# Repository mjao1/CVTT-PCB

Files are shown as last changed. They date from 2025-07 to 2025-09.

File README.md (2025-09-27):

# CVTT-PCB
**Custom Embedded PCB for a Computer Vision-Based Table Tennis Robotic System**

<div align="center">
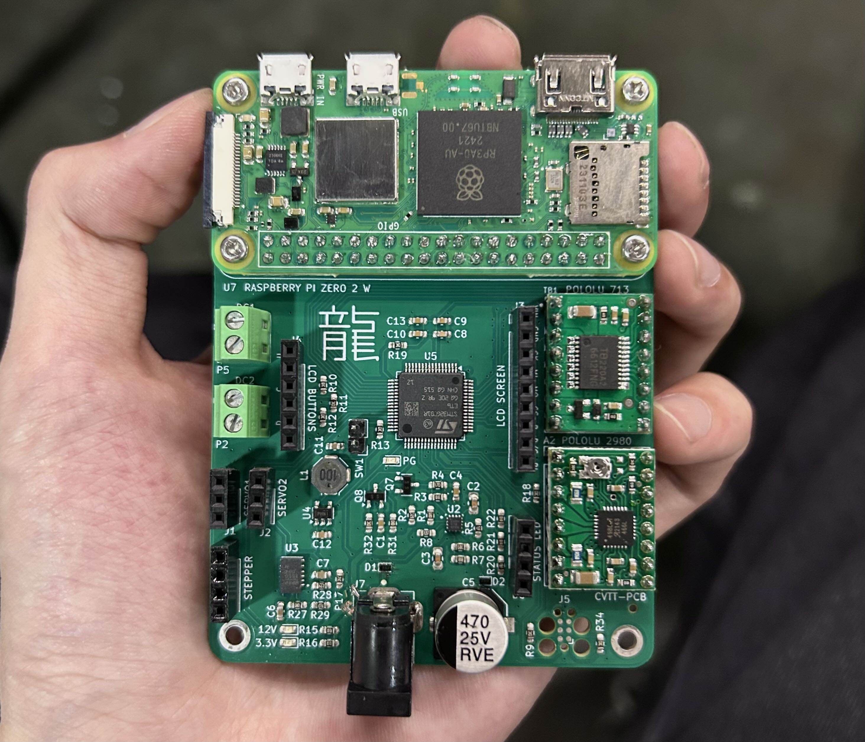
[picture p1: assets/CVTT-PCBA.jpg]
CVTT-PCBA
  
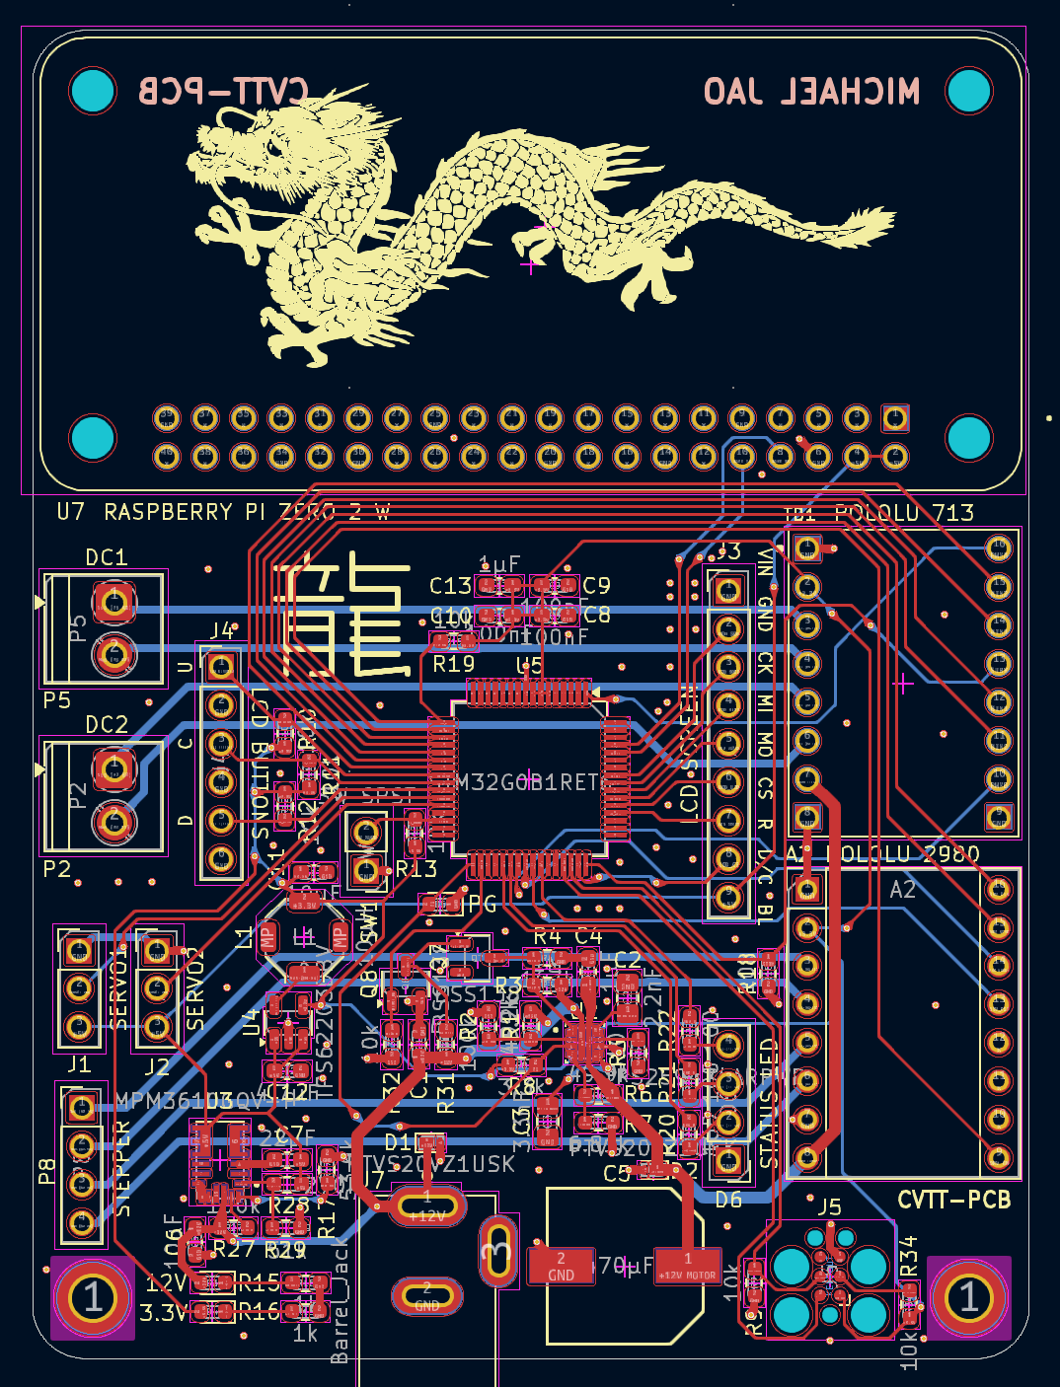
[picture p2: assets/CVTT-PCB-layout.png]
CVTT-PCB-layout
  
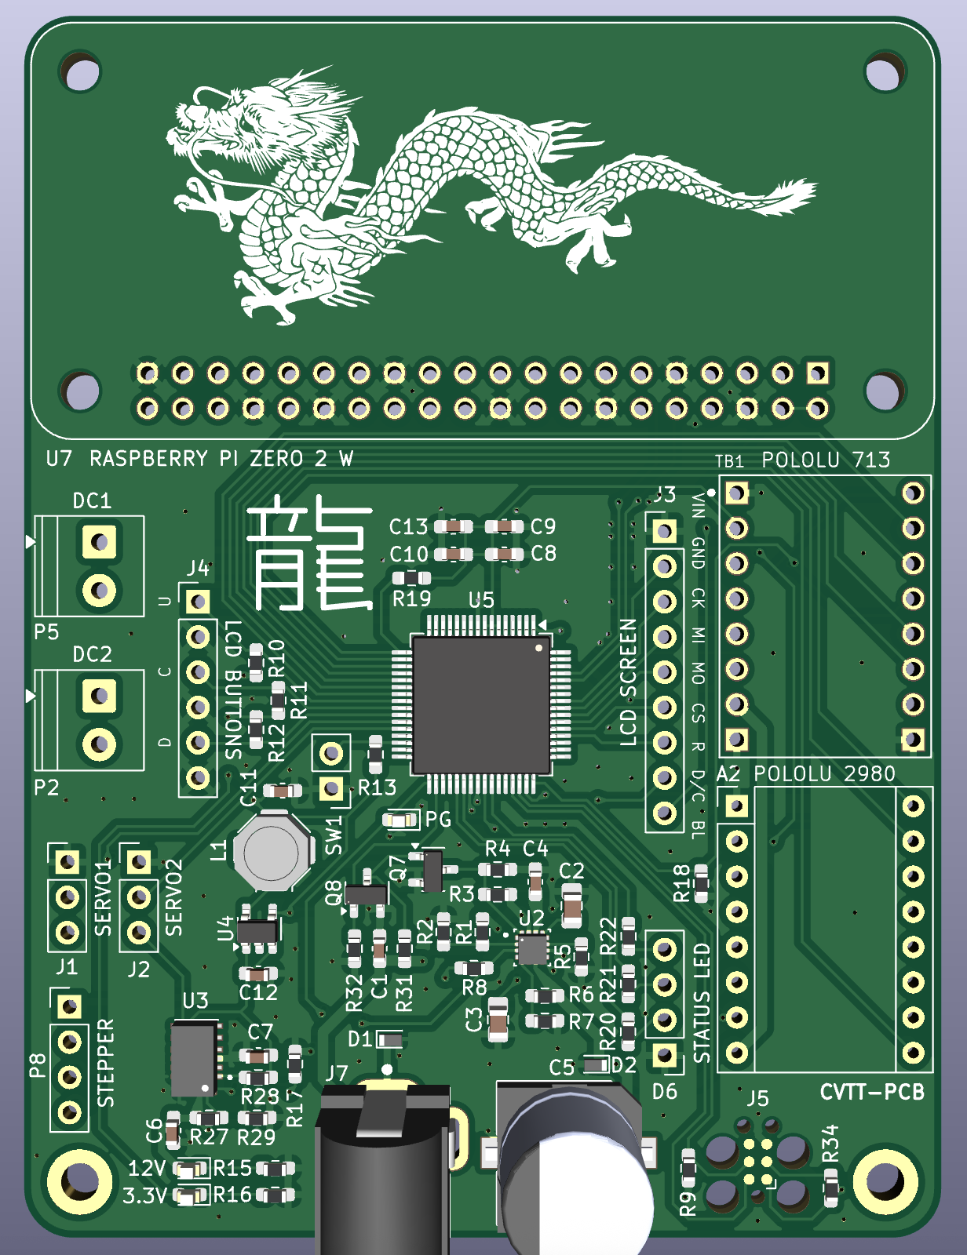
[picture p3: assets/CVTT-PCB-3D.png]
CVTT-PCB-3D
  
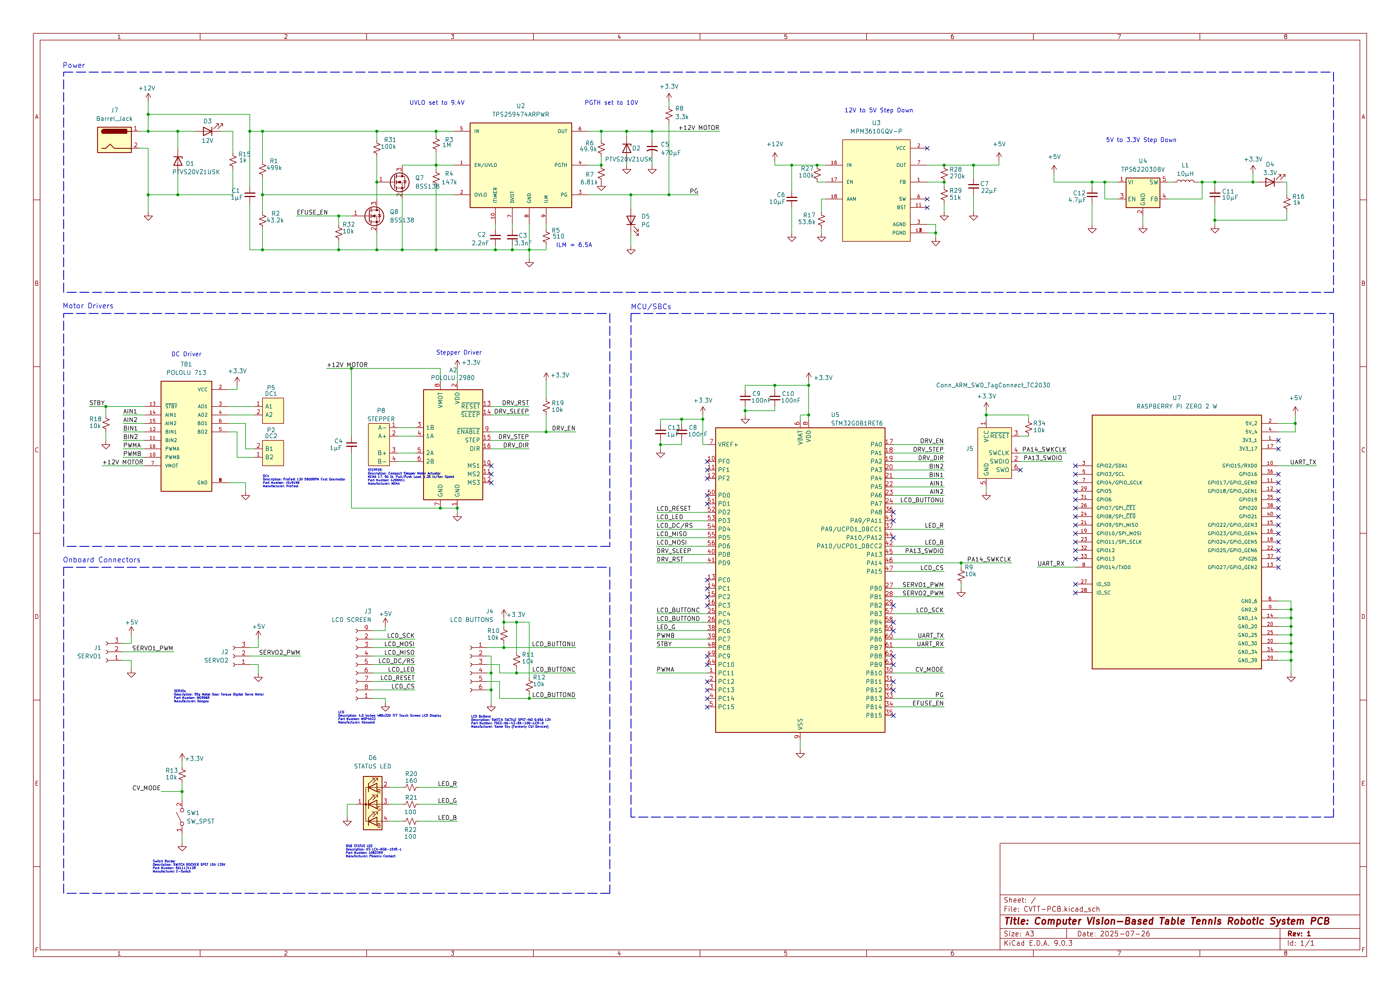
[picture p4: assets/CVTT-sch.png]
CVTT-sch
  
</div>

<div align="center">
<em>The dragon on the silkscreen references Ma Long, the goat of table tennis; 'Long (龍)' translates to 'dragon' from Mandarin.</em>
</div>

## Core Components

- **Microcontrollers and Compute:**
  - STM32G0B1RET6
  - Raspberry Pi Zero 2 W

## Actuation System

- **Motor Driver Support:**
  - 2 Brushless DC motors for flywheels
  - 2 Servos for direction and distance control
  - 1 Stepper motor for ball feeding

## Power and Regulation

- **Power Circuitry:**
  - 12V input
  - E-fuse circuit
  - 12V to 5V LDO Regulator
  - 5V to 3.3V LDO Regulator

## User Interface

- **Controls and Feedback:**
  - Manual/CV mode switch
  - LCD screen for manual control
  - LCD navigation buttons
  - Diagnostic LEDs
 
## STM32G0B1RET6 Pinout

### Inputs
| Signal | Pin |
|---|---|
| UART_RX | PB7 |
| LCD_MISO | PD5 |
| LCD_BUTTONC | PC4 |
| LCD_BUTTOND | PC5 |
| LCD_BUTTONU | PA7 |
| CV_MODE | PB10  |
| PB13 | PB13  |

### Outputs
| Signal | Pin  | Signal | Pin  | Signal | Pin  | Signal | Pin  |
|---|---|---|---|---|---|---|---|
| UART_TX | PB6  | LED_G | PC6  | DRV_EN | PA0  | LED_R | PA9  |
| LCD_RESET | PD2  | PWMB | PC7  | DRV_STEP | PA1  | LED_B | PA10 |
| LCD_LED | PD3  | STBY | PC8  | DRV_DIR | PA2  | LCD_CS | PA15 |
| LCD_DC/RS | PD4  | PWMA | PC11 | BIN2 | PA3  | SERVO1_PWM  | PB0  |
| LCD_MOSI | PD6  | DRV_SLEEP | PD8  | BIN1 | PA4  | SERVO2_PWM  | PB1  |
| LCD_SCK | PB3  | DRV_RST | PD9  | AIN1 | PA5  | EFUSE_EN | PB14 |
| | | | | AIN2 | PA6  | | |

### Tag
| Signal  | Pin |
|---|---|
| SWDIO | PA13  |
| SWKCLK  | PA14  |

## RPI Zero 2 W Pinout

### Inputs
| Signal | Pin |
|---|---|
| SC1174 input | — |
| UART_TX | GPIO15 |

### Outputs
| Signal  | Pin |
|---|---|
| UART_RX | GPIO14 |

## Next Steps
- Programming STM machine logic state machine
  - Design LCD user interface for manual and vision modes
- Programming RPI CV player recognition algorithm
  - Using RPI AI camera (SC1174) for inference acceleration

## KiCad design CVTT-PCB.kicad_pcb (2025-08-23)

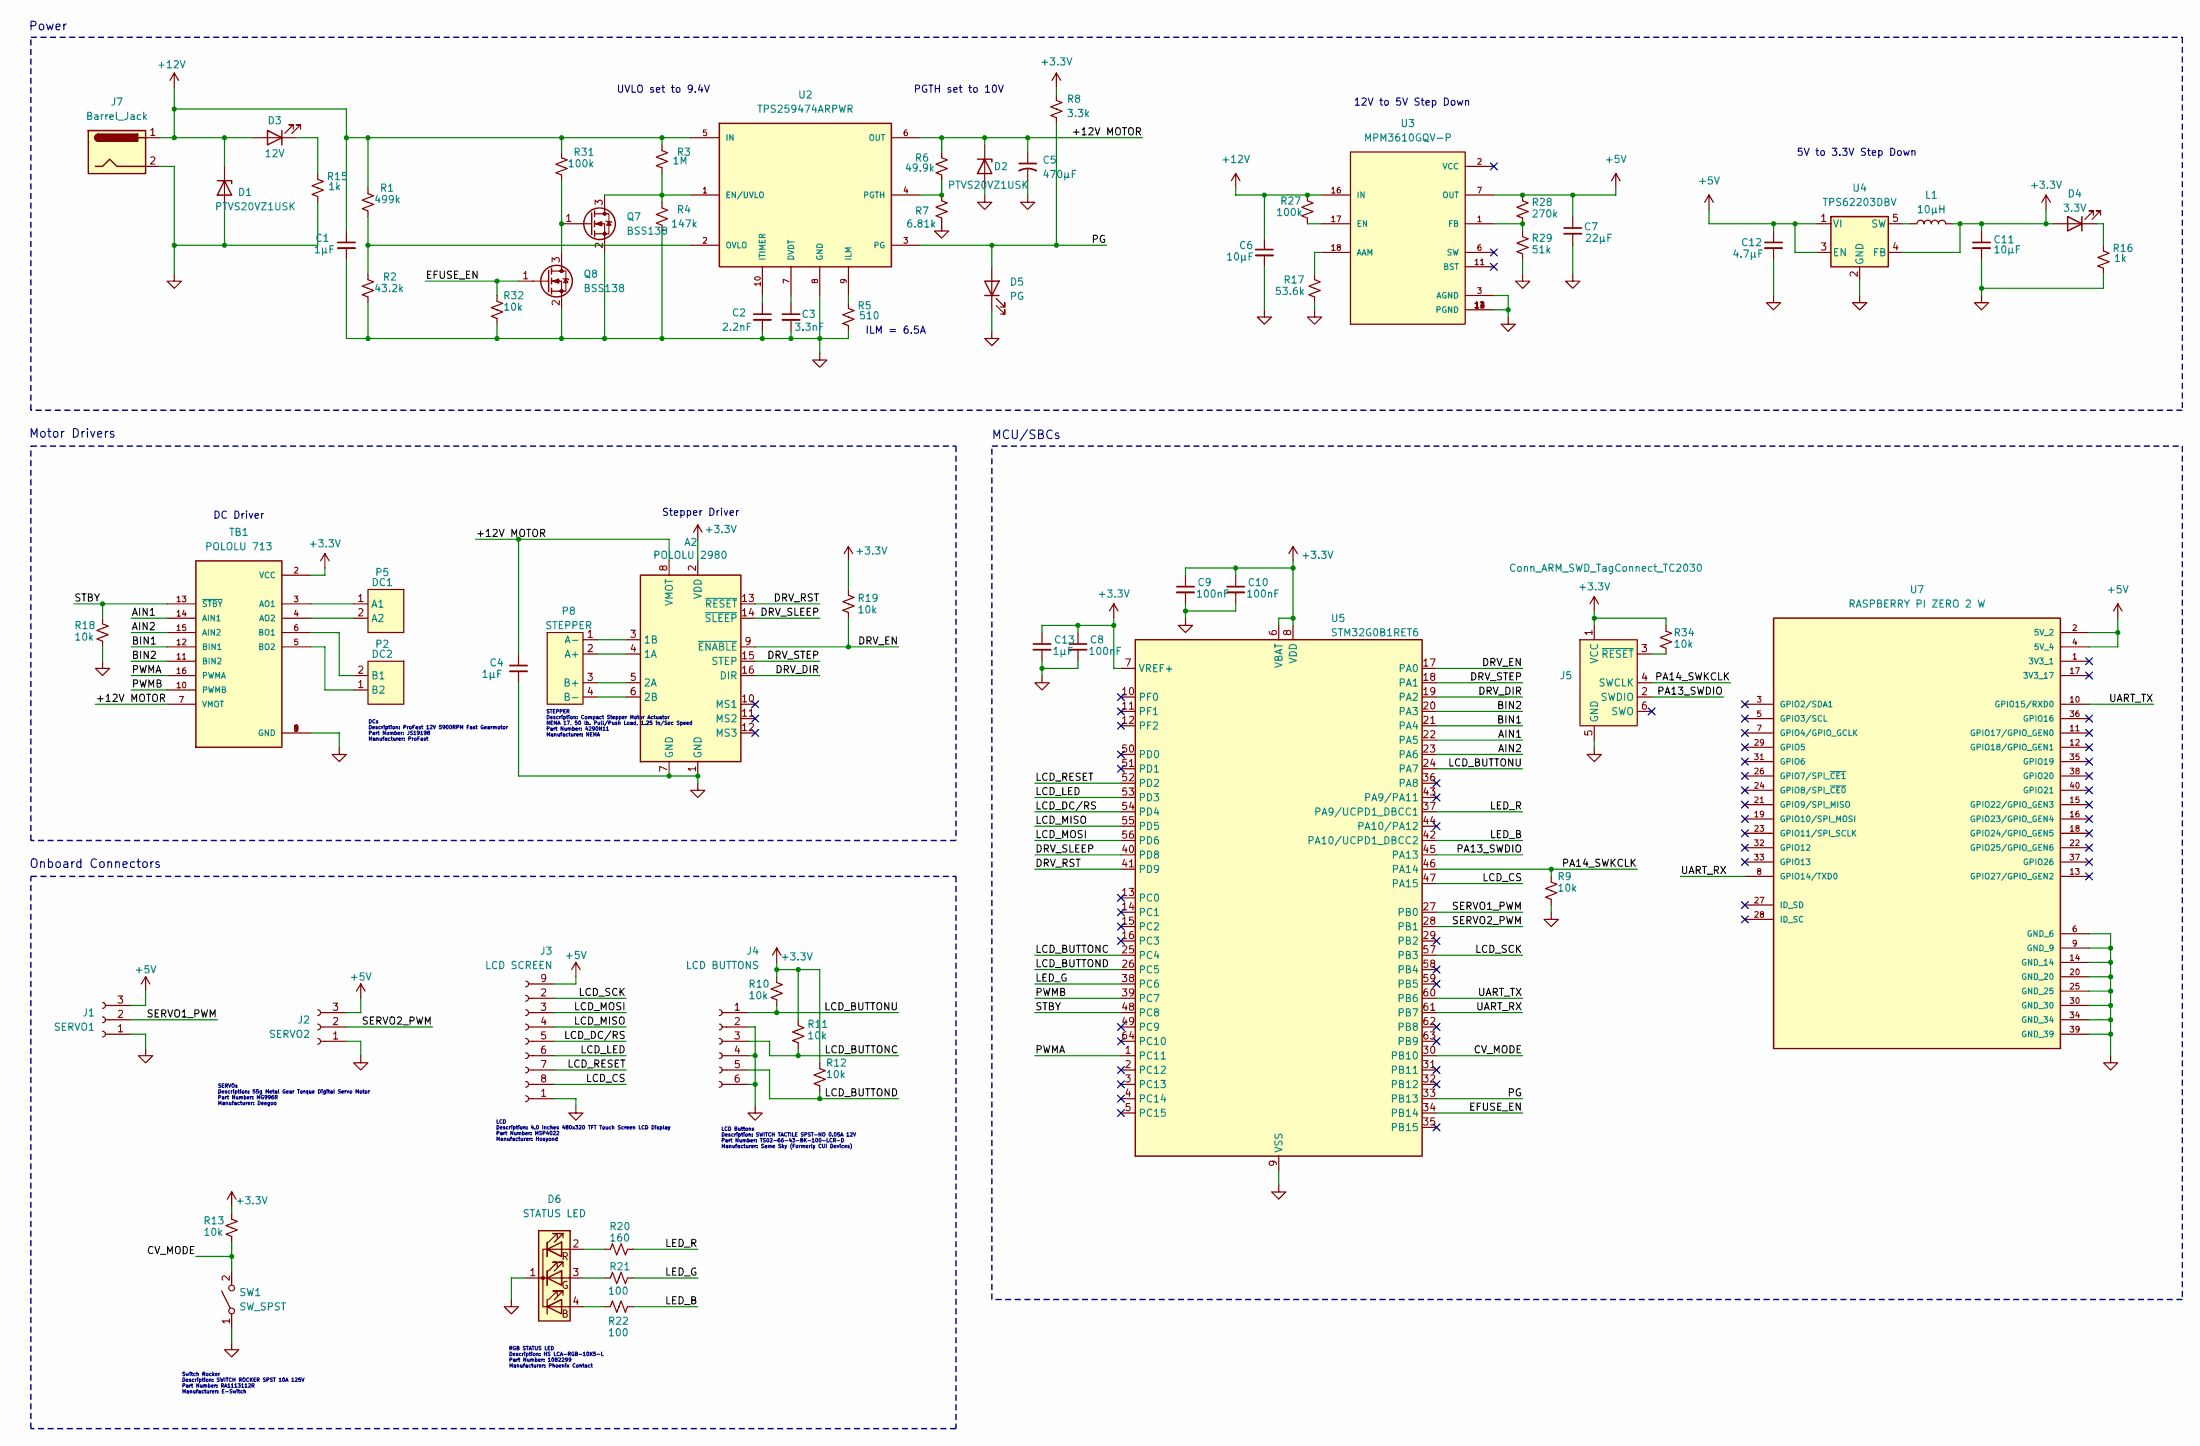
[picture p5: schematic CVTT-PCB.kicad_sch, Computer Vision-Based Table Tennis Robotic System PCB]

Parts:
A2: POLOLU 2980; Pololu_Breakout-16_15.2x20.3mm; Part Number A4988
C1, C4, C13: 1µF; C_0603_1608Metric_Pad1.08x0.95mm_HandSolder; Part Number C0603C105Z3VACTU
C2: 2.2nF; C_0805_2012Metric_Pad1.18x1.45mm_HandSolder; Part Number C0805C222K3GECTU
C3: 3.3nF; C_0805_2012Metric_Pad1.18x1.45mm_HandSolder; Part Number C0805C332F5GECAUTO7210
C5: 470µF; UD_10X10_; Part Number UUD1E471MNL1GS
C6, C11: 10µF; C_0603_1608Metric_Pad1.08x0.95mm_HandSolder; Part Number GRM188R61E106KA73D
C7: 22µF; C_0603_1608Metric_Pad1.08x0.95mm_HandSolder; Part Number CL10A226MO7JZNC
C8, C9, C10: 100nF; C_0603_1608Metric_Pad1.08x0.95mm_HandSolder; Part Number C0603C105Z3VACTU
C12: 4.7µF; C_0603_1608Metric_Pad1.08x0.95mm_HandSolder; Part Number CL10A475KO8NNNC
D1, D2: PTVS20VZ1USK; Nexperia_DSN1608-2_1.6x0.8mm; Part Number PTVS20VZ1USK
D3: 12V; LED_0603_1608Metric; Part Number 150060BS75000
D4: 3.3V; LED_0603_1608Metric; Part Number 150060BS75000
D5: PG; LED_0603_1608Metric; Part Number 150060BS75000
D6: STATUS LED; PinHeader_1x04_P2.54mm_Vertical
J1: SERVO1; PinHeader_1x03_P2.54mm_Vertical
J2: SERVO2; PinHeader_1x03_P2.54mm_Vertical
J3: LCD SCREEN; PinHeader_1x09_P2.54mm_Vertical
J4: LCD BUTTONS; PinHeader_1x06_P2.54mm_Vertical
J5: Conn_ARM_SWD_TagConnect_TC2030; Tag-Connect_TC2030-IDC-FP_2x03_P1.27mm_Vertical
J7: Barrel_Jack; CUI_PJ-002B; Part Number PJ-002B
L1: 10µH; L_Bourns_SRU5016_5.2x5.2mm; Part Number SRU5016-100Y
P2: DC2; TerminalBlock_Phoenix_PT-1,5-2-3.5-H_1x02_P3.50mm_Horizontal
P5: DC1; TerminalBlock_Phoenix_PT-1,5-2-3.5-H_1x02_P3.50mm_Horizontal
P8: STEPPER; PinHeader_1x04_P2.54mm_Vertical; Part Number PH1-04-UA
Q7, Q8: BSS138; SOT-23-3; Part Number BSS138LT3G
R1: 499k; R_0603_1608Metric_Pad0.98x0.95mm_HandSolder; Part Number AF0603FR-07499KL
R2: 43.2k; R_0603_1608Metric_Pad0.98x0.95mm_HandSolder; Part Number RMCF0603FT43K2
R3: 1M; R_0603_1608Metric_Pad0.98x0.95mm_HandSolder; Part Number ERJ-3EKF1004V
R4: 147k; R_0603_1608Metric_Pad0.98x0.95mm_HandSolder; Part Number RMCF0603FT147K
R5: 510; R_0603_1608Metric_Pad0.98x0.95mm_HandSolder; Part Number RC0603FR-07510RL
R6: 49.9k; R_0603_1608Metric_Pad0.98x0.95mm_HandSolder; Part Number RMEF0603FT49K9
R7: 6.81k; R_0603_1608Metric_Pad0.98x0.95mm_HandSolder; Part Number RC0603FR-076K81L
R8: 3.3k; R_0603_1608Metric_Pad0.98x0.95mm_HandSolder; Part Number RMCF0603JT3K30
R9, R10, R11, R12, R13, R18, R19, R32, R34: 10k; R_0603_1608Metric_Pad0.98x0.95mm_HandSolder; Part Number CRCW060310K0FKEE
R15, R16: 1k; R_0603_1608Metric_Pad0.98x0.95mm_HandSolder; Part Number RCS06031K00FKEA
R17: 53.6k; R_0603_1608Metric_Pad0.98x0.95mm_HandSolder; Part Number CRCW060353K6FKEAC
R20: 160; R_0603_1608Metric_Pad0.98x0.95mm_HandSolder; Part Number CRCW060310K0FKEE
R21, R22: 100; R_0603_1608Metric_Pad0.98x0.95mm_HandSolder; Part Number CRCW060310K0FKEE
R27, R31: 100k; R_0603_1608Metric_Pad0.98x0.95mm_HandSolder; Part Number RCS0603100KFKEA
R28: 270k; R_0603_1608Metric_Pad0.98x0.95mm_HandSolder; Part Number RC0603FR-07270KL
R29: 51k; R_0603_1608Metric_Pad0.98x0.95mm_HandSolder; Part Number RC0603FR-1351KL
SW1: SW_SPST; PinHeader_1x02_P2.54mm_Vertical; Part Number SWITCH ROCKER SPST 10A 125V
TB1: POLOLU 713; SHIELD_POLOLU-713; Part Number TB6612FNG
U2: TPS259474ARPWR; IC_TPS25974ARPWR; PARTREV A
U3: MPM3610GQV-P; CONV_MPM3610GQV-P; PARTREV 1.01
U4: TPS62203DBV; SOT-23-5; Part Number TPS62203DBVT
U5: STM32G0B1RET6; LQFP-64_10x10mm_P0.5mm; Part Number STM32G0B1RET6
U7: RASPBERRY PI ZERO 2 W; MODULE_RASPBERRY_PI_ZERO_2_W; PARTREV April 2024

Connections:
+3.3V: A2.2 (VDD), C8.1, C9.1, C10.1, C11.1, C13.1, D4.2 (A), J5.1 (VCC), L1.2, R8.1, R10.1, R11.1, R12.1, R13.1, R19.1, R34.1, TB1.2 (VCC), U4.4 (FB), U5.6 (VBAT), U5.7 (VREF+), U5.8 (VDD)
+5V: C7.1, C12.1, J1.3 (Pin_1), J2.3 (Pin_1), J3.9 (Pin_1), R28.1, U3.7 (OUT), U4.1 (VI), U4.3 (EN), U7.2 (5V_2), U7.4 (5V_4)
+12V: C1.1, C6.1, D1.1 (K), D3.2 (A), J7.1, R1.1, R3.1, R27.1, R31.1, U2.5 (IN), U3.16 (IN)
/+12V MOTOR: A2.8 (VMOT), C4.1, C5.1, D2.1 (K), R6.1, TB1.7 (VMOT), U2.6 (OUT)
/AIN1: TB1.14 (AIN1), U5.22 (PA5)
/AIN2: TB1.15 (AIN2), U5.23 (PA6)
/BIN1: TB1.12 (BIN1), U5.21 (PA4)
/BIN2: TB1.11 (BIN2), U5.20 (PA3)
/CV_MODE: R13.2, SW1.2 (B), U5.30 (PB10)
/DRV_DIR: A2.16 (DIR), U5.19 (PA2)
/DRV_EN: A2.9 (~ENABLE), R19.2, U5.17 (PA0)
/DRV_RST: A2.13 (~RESET), U5.41 (PD9)
/DRV_SLEEP: A2.14 (~SLEEP), U5.40 (PD8)
/DRV_STEP: A2.15 (STEP), U5.18 (PA1)
/EFUSE_EN: Q8.1 (G), R32.1, U5.34 (PB14)
/LCD_BUTTONC: J4.3, R11.2, U5.25 (PC4)
/LCD_BUTTOND: J4.5, R12.2, U5.26 (PC5)
/LCD_BUTTONU: J4.1, R10.2, U5.24 (PA7)
/LCD_CS: J3.8, U5.47 (PA15)
/LCD_DC/RS: J3.5, U5.54 (PD4)
/LCD_LED: J3.6, U5.53 (PD3)
/LCD_MISO: J3.4, U5.55 (PD5)
/LCD_MOSI: J3.3, U5.56 (PD6)
/LCD_RESET: J3.7, U5.52 (PD2)
/LCD_SCK: J3.2, U5.57 (PB3)
/LED_B: R22.2, U5.42 (PA10/UCPD1_DBCC2)
/LED_G: R21.2, U5.38 (PC6)
/LED_R: R20.2, U5.37 (PA9/UCPD1_DBCC1)
/PA13_SWDIO: J5.2 (SWDIO), U5.45 (PA13)
/PA14_SWKCLK: J5.4 (SWCLK), R9.1, U5.46 (PA14)
/PG: D5.2 (A), R8.2, U2.3 (PG), U5.33 (PB13)
/PWMA: TB1.16 (PWMA), U5.1 (PC11)
/PWMB: TB1.10 (PWMB), U5.39 (PC7)
/SERVO1_PWM: J1.2, U5.27 (PB0)
/SERVO2_PWM: J2.2, U5.28 (PB1)
/STBY: R18.1, TB1.13 (~STBY), U5.48 (PC8)
/UART_RX: U5.61 (PB7), U7.8 (GPIO14/TXD0)
/UART_TX: U5.60 (PB6), U7.10 (GPIO15/RXD0)
GND: A2.1 (GND), A2.7 (GND), C1.2, C2.2, C3.2, C4.2, C5.2, C6.2, C7.2, C8.2, C9.2, C10.2, C11.2, C12.2, C13.2, D1.2 (A), D2.2 (A), D5.1 (K), D6.1 (K), J1.1 (Pin_3), J2.1 (Pin_3), J3.1 (Pin_9), J4.2, J4.4, J4.6, J5.5 (GND), J7.2, Q7.2 (S), Q8.2 (S), R2.2, R4.2, R5.2, R7.2, R9.2, R15.2, R16.2, R17.2, R18.2, R29.2, R32.2, SW1.1 (A), TB1.1 (GND), TB1.8 (GND), TB1.9 (GND), U2.8 (GND), U3.3 (AGND), U3.12 (PGND), U3.13 (PGND), U3.14 (PGND), U4.2 (GND), U5.9 (VSS), U7.6 (GND_6), U7.9 (GND_9), U7.14 (GND_14), U7.20 (GND_20), U7.25 (GND_25), U7.30 (GND_30), U7.34 (GND_34), U7.39 (GND_39)
unnamed: A2.4 (1A), P8.2 (A+)
unnamed: A2.3 (1B), P8.1 (A-)
unnamed: A2.5 (2A), P8.3 (B+)
unnamed: A2.6 (2B), P8.4 (B-)
unnamed: D3.1 (K), R15.1
unnamed: D4.1 (K), R16.1
unnamed: D6.4 (BA), R22.1
unnamed: D6.3 (GA), R21.1
unnamed: D6.2 (RA), R20.1
unnamed: J5.3 (~RESET), R34.2
unnamed: P2.2 (B1), TB1.6 (BO1)
unnamed: P2.1 (B2), TB1.5 (BO2)
unnamed: P5.1 (A1), TB1.3 (AO1)
unnamed: P5.2 (A2), TB1.4 (AO2)
unnamed: Q7.3 (D), R3.2, R4.1, U2.1 (EN/UVLO)
unnamed: Q7.1 (G), Q8.3 (D), R31.2
unnamed: C3.1, U2.7 (DVDT)
unnamed: R5.1, U2.9 (ILM)
unnamed: C2.1, U2.10 (ITIMER)
unnamed: R1.2, R2.1, U2.2 (OVLO)
unnamed: R6.2, R7.1, U2.4 (PGTH)
unnamed: R17.1, U3.18 (AAM)
unnamed: R27.2, U3.17 (EN)
unnamed: R28.2, R29.1, U3.1 (FB)
unnamed: L1.1, U4.5 (SW)

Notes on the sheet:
MCU/SBCs
STEPPER Description: Compact Stepper Motor Actuator NEMA 17, 50 lb. Pull/Push Load, 1.25 in/Sec Speed Part Number: 4290N11 Manufacturer: NEMA
RGB STATUS LED Description: HS LCA-RGB-10X5-L Part Number: 1082299 Manufacturer: Phoenix Contact
UVLO set to 9.4V
Switch Rocker Description: SWITCH ROCKER SPST 10A 125V Part Number: RA1113112R Manufacturer: E-Switch
Motor Drivers
PGTH set to 10V
SERVOs Description: 55g Metal Gear Torque Digital Servo Motor Part Number: MG996R Manufacturer: Deegoo
ILM = 6.5A
5V to 3.3V Step Down
LCD Buttons Description: SWITCH TACTILE SPST-NO 0.05A 12V Part Number: TS02-66-43-BK-100-LCR-D Manufacturer: Same Sky (Formerly CUI Devices)
Stepper Driver
DCs Description: ProFast 12V 5900RPM Fast Gearmotor Part Number: JS19198 Manufacturer: ProFast
Power
LCD Description: 4.0 Inches 480x320 TFT Touch Screen LCD Display Part Number: MSP4022 Manufacturer: Hosyond
Onboard Connectors
DC Driver
12V to 5V Step Down

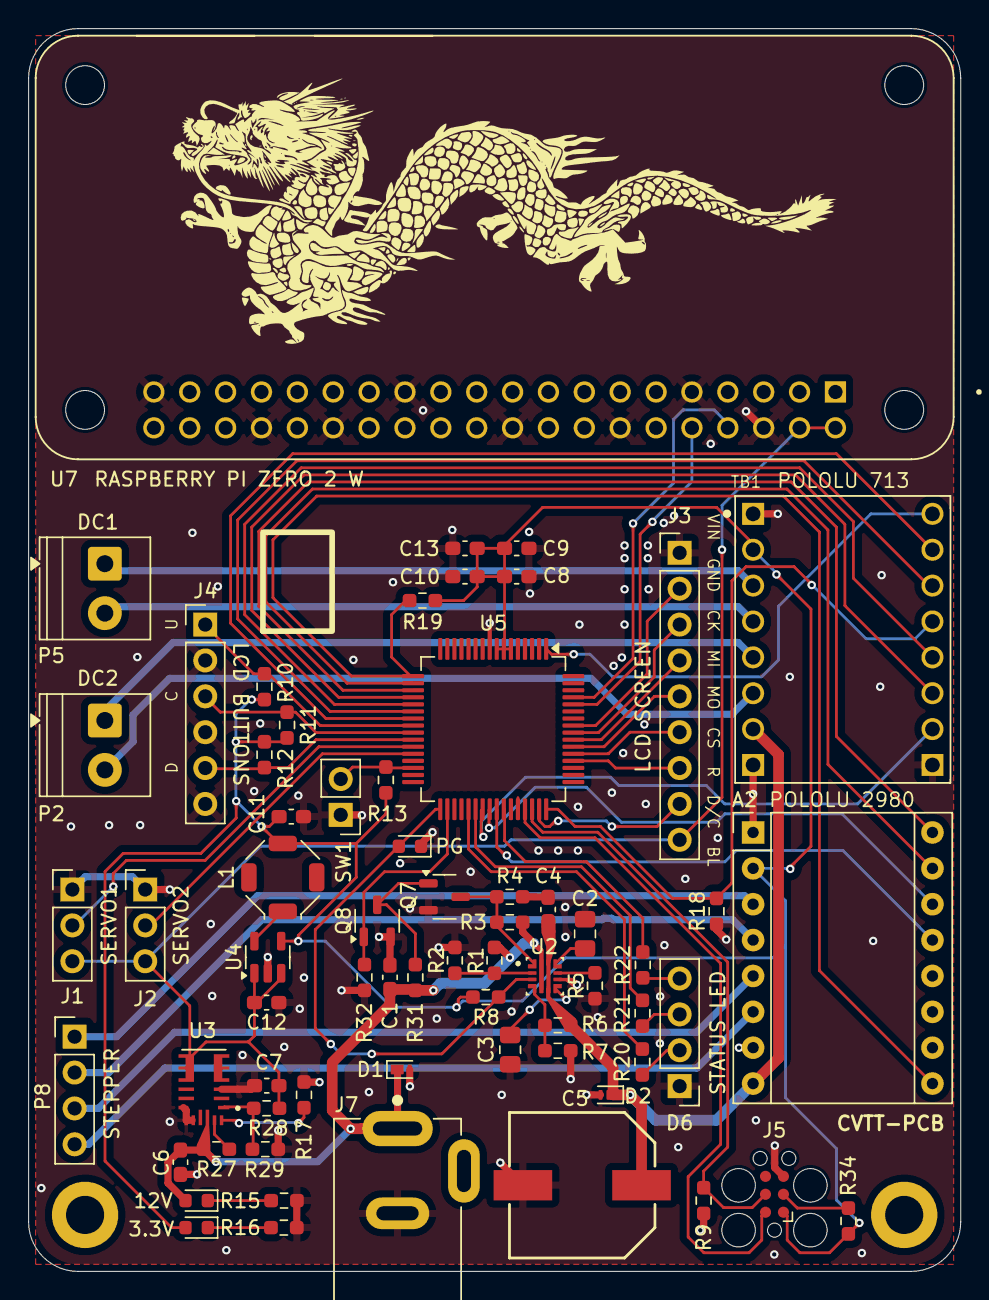
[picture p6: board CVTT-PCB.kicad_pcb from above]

Board: 4 copper layers, 66.0 x 88.0 mm, 66 parts (0 on the bottom side), 64 nets.

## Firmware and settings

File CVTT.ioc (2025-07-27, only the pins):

Mcu.UserName=STM32G0B1RETx
PA0.Signal=GPIO_Output
PA1.Signal=GPIO_Output
PA10.Signal=GPIO_Output
PA13.Signal=SYS_SWDIO
PA14-BOOT0.Signal=SYS_SWCLK
PA15.Signal=SPI1_NSS
PA2.Signal=GPIO_Output
PA3.Signal=GPIO_Output
PA4.Signal=GPIO_Output
PA5.Signal=GPIO_Output
PA6.Signal=GPIO_Output
PA7.Signal=GPIO_Input
PA9.Signal=GPIO_Output
PB0.Signal=S_TIM3_CH3
PB1.Signal=S_TIM3_CH4
PB10.Signal=GPIO_Input
PB13.Signal=GPIO_Input
PB14.Signal=GPIO_Output
PB3.Signal=SPI1_SCK
PB6.Signal=USART1_TX
PB7.Signal=USART1_RX
PC11.Signal=S_TIM1_CH4
PC4.Signal=GPIO_Input
PC5.Signal=GPIO_Input
PC6.Signal=GPIO_Output
PC7.Signal=S_TIM2_CH4
PC8.Signal=GPIO_Output
PD2.Signal=GPIO_Output
PD3.Signal=GPIO_Output
PD4.Signal=GPIO_Output
PD5.Signal=SPI1_MISO
PD6.Signal=SPI1_MOSI
PD8.Signal=GPIO_Output
PD9.Signal=GPIO_Output

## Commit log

2025-07-22 Add LED indicators
    [CVTT-PCB.kicad_pcb, CVTT-PCB.kicad_sch]
2025-07-25 Update schem and layout
    [CVTT-PCB.kicad_pcb, CVTT-PCB.kicad_sch]
2025-07-25 Update pinout
    [CVTT-PCB.kicad_pcb, CVTT-PCB.kicad_sch]
2025-07-26 add RGB led status indicator
    [CVTT-PCB.kicad_pcb, CVTT-PCB.kicad_sch]
2025-07-26 update layout
    [CVTT-PCB.kicad_pcb]
2025-07-26 update assets
    [CVTT-PCB.kicad_pcb]
2025-07-27 usb replacement
    [CVTT-PCB.kicad_pcb, CVTT-PCB.kicad_sch]
2025-07-27 update sch
    [CVTT-PCB.kicad_sch]
2025-07-31 update layout labeling
    [CVTT-PCB.kicad_pcb]
2025-08-02 fix MPM3610GQV-P resistors
    [CVTT-PCB.kicad_pcb, CVTT-PCB.kicad_sch]
2025-08-02 remove pg led
    [CVTT-PCB.kicad_pcb, CVTT-PCB.kicad_sch]
2025-08-06 new pg
    [CVTT-PCB.kicad_pcb, CVTT-PCB.kicad_sch]
2025-08-07 reconfigure ILM for motor req
    [CVTT-PCB.kicad_pcb, CVTT-PCB.kicad_sch]
2025-08-10 resolve DRC errors
    [CVTT-PCB.kicad_pcb, CVTT-PCB.kicad_sch]
2025-08-10 final check before gerbers
    [CVTT-PCB.kicad_pcb, CVTT-PCB.kicad_sch]
2025-08-10 pg placement
    [CVTT-PCB.kicad_pcb]
2025-08-15 update sch info
    [CVTT-PCB.kicad_sch]
2025-08-19 edit sch
    [CVTT-PCB.kicad_pcb, CVTT-PCB.kicad_sch]
2025-08-23 edit pcb
    [CVTT-PCB.kicad_pcb]
2025-09-09 Add PCBA image
